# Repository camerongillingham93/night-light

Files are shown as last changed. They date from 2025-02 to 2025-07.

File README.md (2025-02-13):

# Firefly Night-Light
#### February, 13, 2025
 - Development REPO for a nightlight project using the AT-TINY1614 MCU and addressable LED strips
## Features 
 - PCB is designed to replace a standard wide-mouth Mason jar and have LED strips hanging from it resembling a jar full of fireflies
 - Top copper pad acts as a touch button to toggle the nightlight on/off and adjust brightness. Shake the jar for a firefly lightshow
 - Onboard LI-PO battery that is USB-C re-chargeable

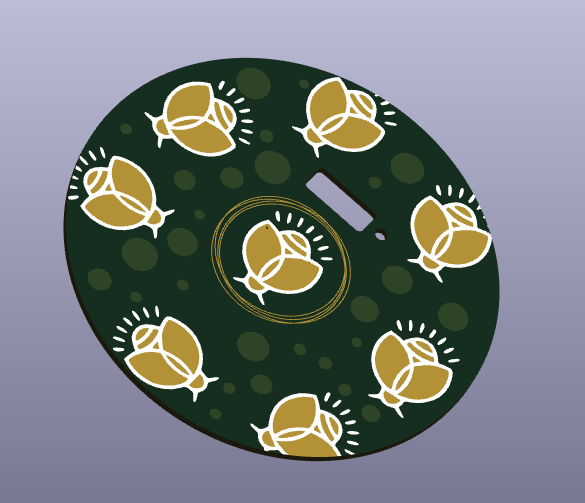
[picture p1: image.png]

<br>
*Rendering of Top of the night-light PCB*

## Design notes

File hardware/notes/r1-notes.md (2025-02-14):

# Nightlight Rev 1 Notes
### February, 13, 2025

## Assembly  Notes

- Get stencil and use hot plate for next order, voltage regulator was very challenging to hand solder and bridged many times before successfully soldering. 

- Was missing 10K 1210 SMT resistors from order, R1,R2,R6

- Need to think of a better method for attaching LED strips or use different part, they are very thin and challenging t

## Testing

Voltage regulator - PAM2401SCADJ
- Once soldered succesfully, swept the Vin range given by the data sheet and had a steady 5V output

Charge controller - MCP73831-2-OT
- Discharged a 3800 mAh 3.7 li-ion to 3.6V 
- scraped open the Vbatt trace leading to the charge controller to measure current
- Set up meters to measure Vbatt and Ibatt
- plugged in USB cable and monitored output 
- I out was 100mA and stayed at the current until Vbatt was 4.2V, At this point Ibatt started to lower until ~60mA and maintained a voltage of 4.2. This is as expected with a 10K resistor on PROG pin. 

MCU ATtiny1614-SS
- Flashed the ATTINY via serial UPDI with a cp2021 USB-UART module
- Instructions @ https://github.com/SpenceKonde/AVR-Guidance/blob/master/UPDI/jtag2updi.md
- tested by placing a LED across switch pin and running a BLINK script.
- for development i have broken out the serial pins on the MCU. USB to UART is solderded to a dedicated perf board that can switch between UPDI to program and serial comms for troubleshooting. 

## Next time TODO

- Ground was missed on charge controller IC
- Add decoupling caps to MCU
- add 0 OHM R to separate regulator and charge controller for testing
- Use a bi-colour LED on the STAT pin of the charge controller
- Use ADC on MCU to measure Vbatt and disable nightlight at low voltage threshold and prompt charge somehow, OR find a solution to use a pin from the power supply for some sort of LVD
    - Design a 2:1 Voltage divider on the ADC input. Although i dont think it is needed as a Vref can be either internal(selectable) or VDD, in which case place a 0ohm inline.
- find a better USB-C port that actually uses CC resistors so product will work with PD
- breakout serial pins for comms with the board
- try to wire up PTC to touch pad with 0ohm
- Add a reset button

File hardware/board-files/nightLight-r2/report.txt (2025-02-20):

Info: Processing symbol 'B1:myFootprintDesigns:fireflyTouch'.
Info: Processing symbol 'U3:Package_TO_SOT_SMD:SOT-23-5'.
Info: Processing symbol 'U2:Package_SO:SOIC-14_3.9x8.7mm_P1.27mm'.
Info: Processing symbol 'BT1:myFootprintDesigns:14500 Holder'.
Info: Processing symbol 'C1:Capacitor_SMD:C_1206_3216Metric'.
Info: Processing symbol 'SW2:Connector_PinHeader_2.54mm:PinHeader_2x01_P2.54mm_Vertical_SMD'.
Info: Processing symbol 'S1:PTS526_SM08_SMTR2_LFS:SW_PTS526_SM08_SMTR2_LFS'.
Info: Processing symbol 'C2:Capacitor_SMD:C_1206_3216Metric'.
Info: Processing symbol 'R11:Resistor_SMD:R_1206_3216Metric'.
Info: Processing symbol 'R10:Resistor_SMD:R_1206_3216Metric'.
Info: Processing symbol 'C3:Capacitor_SMD:C_1206_3216Metric'.
Info: Processing symbol 'C4:Capacitor_SMD:C_1206_3216Metric'.
Info: Processing symbol 'C5:Capacitor_SMD:C_1206_3216Metric'.
Info: Processing symbol 'R9:Resistor_SMD:R_1206_3216Metric'.
Info: Processing symbol 'R8:Resistor_SMD:R_1206_3216Metric'.
Info: Processing symbol 'C6:Capacitor_SMD:C_1206_3216Metric'.
Info: Processing symbol 'R7:Resistor_SMD:R_1206_3216Metric'.
Info: Processing symbol 'R6:Resistor_SMD:R_1206_3216Metric'.
Info: Processing symbol 'R5:Resistor_SMD:R_1206_3216Metric'.
Info: Processing symbol 'R4:Resistor_SMD:R_1206_3216Metric'.
Info: Processing symbol 'R3:Resistor_SMD:R_1206_3216Metric'.
Info: Processing symbol 'R2:Resistor_SMD:R_1206_3216Metric'.
Info: Processing symbol 'R1:Resistor_SMD:R_1206_3216Metric'.
Info: Processing symbol 'C7:Capacitor_SMD:C_1206_3216Metric'.
Info: Processing symbol 'L1:SRN2510BTA-2R2M:SRN2510BTA2R2M'.
Info: Processing symbol 'J8:Connector_PinSocket_2.54mm:PinSocket_1x05_P2.54mm_Vertical_SMD_Pin1Left'.
Info: Processing symbol 'J6:Connector_PinHeader_2.54mm:PinHeader_1x03_P2.54mm_Vertical_SMD_Pin1Left'.
Info: Processing symbol 'J5:myFootprintDesigns:USB-C_PWR'.
Info: Processing symbol 'J3:Connector_PinHeader_2.54mm:PinHeader_1x03_P2.54mm_Vertical_SMD_Pin1Left'.
Info: Processing symbol 'J2:Connector_PinHeader_2.54mm:PinHeader_1x03_P2.54mm_Vertical_SMD_Pin1Left'.
Info: Processing symbol 'J1:Connector_PinHeader_2.54mm:PinHeader_1x03_P2.54mm_Vertical_SMD_Pin1Left'.
Info: Processing symbol 'D1:IN-S124ARUW:LED_IN-S124ARUW'.
Info: Processing symbol 'IC1:PAM2401:SOP65P490X110-8N'.
Reconnected IC1 pin 3 from VBATT to Net-(IC1-VIN).
Connected C7 pin 2 to GND.
Add net LED_DATA.
Reconnected J1 pin 2 from Net-(J1-Pin_2) to LED_DATA.
Connected C7 pin 1 to +5V.
Updated C7 properties.
Updated C7 symbol association from  to /aaa6ea5b-403b-4111-be4f-55c8a439cf0b.
Added J5 (footprint 'myFootprintDesigns:USB-C_PWR').
Changed REF** reference designator to J5.
Changed J5 value from USB-C_PWR to USB_C_Receptacle_PowerOnly_6P.
Updated J5 symbol association from  to /313a628f-e523-4211-801d-f47782c87484.
Updated J5 properties.
Add net Net-(J5-CC1).
Connected J5 pin A5 to Net-(J5-CC1).
Connected J5 pin A9 to Net-(U3-V_{DD}).
Connected J5 pin A12 to GND.
Add net Net-(J5-CC2).
Connected J5 pin B5 to Net-(J5-CC2).
Changed C7 value from C_1206_3216Metric to 22uF.
Added J6 (footprint 'Connector_PinHeader_2.54mm:PinHeader_1x03_P2.54mm_Vertical_SMD_Pin1Left').
Changed REF** reference designator to J6.
Changed J6 value from PinHeader_1x03_P2.54mm_Vertical_SMD_Pin1Left to Conn_01x03.
Updated J6 symbol association from  to /cc5e9cfa-e928-4264-b735-3705385eb68d.
Updated J6 properties.
Add net PA_1.
Connected J6 pin 1 to PA_1.
Add net PA_2.
Connected J6 pin 2 to PA_2.
Add net PA_3.
Connected J6 pin 3 to PA_3.
Changed REF** reference designator to C7.
Added J8 (footprint 'Connector_PinSocket_2.54mm:PinSocket_1x05_P2.54mm_Vertical_SMD_Pin1Left').
Changed REF** reference designator to J8.
Changed J8 value from PinSocket_1x05_P2.54mm_Vertical_SMD_Pin1Left to Conn_01x05_Pin.
Updated J8 symbol association from  to /a5c941a7-82e7-435c-9ba5-a8ea3b5d0ae3.
Updated J8 properties.
Connected J8 pin 1 to GND.
Add net TX.
Connected J8 pin 2 to TX.
Add net RX.
Connected J8 pin 3 to RX.
Add net UPDI.
Connected J8 pin 4 to UPDI.
Connected J8 pin 5 to +5V.
Added C7 (footprint 'Capacitor_SMD:C_1206_3216Metric').
Reconnected L1 pin 1 from VBATT to Net-(IC1-VIN).
Connected C6 pin 2 to GND.
Changed R1 value from 10k to 1M.
Add net Send.
Reconnected R1 pin 1 from Net-(U2-PA5) to Send.
Reconnected R1 pin 2 from Net-(U2-PA6) to Return.
Connected C6 pin 1 to +5V.
Add net Tilt_SW.
Reconnected R2 pin 2 from Net-(U2-PA7) to Tilt_SW.
Updated C6 properties.
Reconnected R3 pin 1 from VBATT to Net-(IC1-VIN).
Updated C6 symbol association from  to /1a6fa1bd-9f4d-40e3-aad2-769d0811d651.
Changed C6 value from C_1206_3216Metric to 22uF.
Changed REF** reference designator to C6.
Added C6 (footprint 'Capacitor_SMD:C_1206_3216Metric').
Reconnected R7 pin 1 from Net-(U1-V+) to Net-(U3-V_{DD}).
Reconnected C5 pin 1 from Net-(U1-V+) to Net-(U3-V_{DD}).
Added R8 (footprint 'Resistor_SMD:R_1206_3216Metric').
Changed REF** reference designator to R8.
Changed R8 value from R_1206_3216Metric to 5.1k.
Updated R8 symbol association from  to /2a3b3306-2b1f-47dc-9f0e-92f4898f2bf4.
Updated R8 properties.
Connected R8 pin 1 to Net-(J5-CC2).
Connected R8 pin 2 to GND.
Add net Net-(U3-V_{DD}).
Added R9 (footprint 'Resistor_SMD:R_1206_3216Metric').
Changed REF** reference designator to R9.
Changed R9 value from R_1206_3216Metric to 5.1k.
Updated R9 symbol association from  to /3f4016df-daa6-43f8-9075-7b56907655ad.
Updated R9 properties.
Connected R9 pin 1 to Net-(J5-CC1).
Connected R9 pin 2 to GND.
Updated C2 symbol association from /f2f016f0-e33d-4f4f-93c3-e3167ada6333 to /1f779e93-5f75-473e-9afa-ae6fad9b06e3.
Added R10 (footprint 'Resistor_SMD:R_1206_3216Metric').
Changed REF** reference designator to R10.
Changed R10 value from R_1206_3216Metric to 10k.
Updated R10 symbol association from  to /bb20765d-0209-4473-9338-8d07f0b34927.
Updated R10 properties.
Connected R10 pin 1 to +5V.
Add net RST_SW.
Connected R10 pin 2 to RST_SW.
Changed C2 value from 22uF to 0.1uF.
Added R11 (footprint 'Resistor_SMD:R_1206_3216Metric').
Changed REF** reference designator to R11.
Changed R11 value from R_1206_3216Metric to 0.
Updated R11 symbol association from  to /f047d941-6963-4854-815e-351e46250964.
Updated R11 properties.
Connected R11 pin 1 to Net-(IC1-VIN).
Connected R11 pin 2 to VBATT.
Reconnected C1 pin 1 from VBATT to Net-(IC1-VIN).
Added S1 (footprint 'PTS526_SM08_SMTR2_LFS:SW_PTS526_SM08_SMTR2_LFS').
Changed REF** reference designator to S1.
Changed S1 value from SW_PTS526_SM08_SMTR2_LFS to PTS526_SM08_SMTR2_LFS.
Updated S1 symbol association from  to /87c368d1-e28a-492d-950a-39ae2efabe5e.
Updated S1 properties.
Connected S1 pin 1 to GND.
Connected S1 pin 3 to RST_SW.
Connected S1 pin 2 to GND.
Connected S1 pin 4 to RST_SW.
Add net Net-(IC1-VIN).
Reconnected SW2 pin 1 from Net-(U2-PA7) to Tilt_SW.
Reconnected B1 pin 1 from Net-(U2-PA6) to Return.
Add net Batt_M.
Reconnected U2 pin 2 from Net-(J1-Pin_2) to Batt_M.
Reconnected U2 pin 3 from Net-(U2-PA5) to Send.
Reconnected U2 pin 4 from Net-(U2-PA6) to Return.
Reconnected U2 pin 5 from Net-(U2-PA7) to Tilt_SW.
Reconnected U2 pin 6 from unconnected-(U2-PB3-Pad6) to RX.
Reconnected U2 pin 7 from unconnected-(U2-PB2-Pad7) to TX.
Reconnected U2 pin 8 from unconnected-(U2-PB1-Pad8) to LED_DATA.
Reconnected U2 pin 9 from unconnected-(U2-PB0-Pad9) to RST_SW.
Reconnected U2 pin 10 from Net-(J4-Pin_2) to UPDI.
Reconnected U2 pin 11 from unconnected-(U2-PA1-Pad11) to PA_1.
Reconnected U2 pin 12 from unconnected-(U2-PA2-Pad12) to PA_2.
Reconnected U2 pin 13 from unconnected-(U2-PA3-Pad13) to PA_3.
Add net Return.
Reconnected U3 pin 4 from Net-(U1-V+) to Net-(U3-V_{DD}).
Removed unused footprint U1.
Removed unused footprint J4.
Removed unused footprint REF**.
Removed unused footprint REF**.
Removed unused footprint REF**.
Removed unused footprint REF**.
Removed unused footprint REF**.
Removed unused footprint REF**.
Removed unused footprint REF**.
Removed unused net unconnected-(U2-PB3-Pad6).
Removed unused net unconnected-(U2-PB2-Pad7).
Removed unused net unconnected-(U2-PB1-Pad8).
Removed unused net Net-(J1-Pin_2).
Removed unused net Net-(J4-Pin_2).
Removed unused net Net-(U1-V+).
Removed unused net Net-(U2-PA5).
Removed unused net Net-(U2-PA6).
Removed unused net Net-(U2-PA7).
Removed unused net unconnected-(U2-PA1-Pad11).
Removed unused net unconnected-(U2-PA2-Pad12).
Removed unused net unconnected-(U2-PA3-Pad13).
Removed unused net unconnected-(U2-PB0-Pad9).
Error: J5 pad S1 not found in myFootprintDesigns:USB-C_PWR.
Error: J5 pad B9 not found in myFootprintDesigns:USB-C_PWR.
Error: J5 pad B12 not found in myFootprintDesigns:USB-C_PWR.

Info: Total warnings: 0, errors: 3.

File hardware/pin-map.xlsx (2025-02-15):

Night Light Pin Map
Pin Number | Pin Name | Use
1 | VDD | PWR
2 | PA4 | Vmeasure ADC1
3 | PA5 | Touch Send
4 | PA6 | Touch Return OR PTC
5 | PA7 | TILT SW
6 | PB3 | RX
7 | PB2 | TX
8 | PB1 | LED Data
9 | PB0 | Rst BTN (Software)
10 | PA0/RESET/UPDI | UPDI
11 | PA1 | spare
12 | PA2 | spare
13 | PA3 | spare
14 | GND | GND

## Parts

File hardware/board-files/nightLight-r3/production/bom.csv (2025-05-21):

Designator | Footprint | Quantity | Value | LCSC Part #
B1 | fireflyTouch | 1 | ~
BT1 | 14500 Holder | 1 | Battery_Cell
C1, C7 | 0805 | 2 | 0.1uF
C2, C3, C6 | 0805 | 3 | 22uF
C4, C5 | 0805 | 2 | 4.7uF
D1 | SOT23-R | 1 | BAT54C
FID1 | Fiducial_1.5mm_Mask3mm | 1 | Fiducial
IC1 | SOP65P490X110-8N | 1 | PAM2401SCADJ
IC2 | SON50P300X300X100-11N-D | 1 | MCP73123T-22SI_MF
J1 | USB-C_PWR | 1 | USB_C_Receptacle_PowerOnly_6P
J2 | PinSocket_1x05_P2.54mm_Vertical_SMD_Pin1Left | 1 | Conn_01x05_Pin
J3 | spares_1*3 | 1 | Conn_01x03
J4, J5, J6 | fairy_conn | 3 | Conn_01x03
L1 | SRN2510BTA2R2M | 1 | SRN2510BTA-2R2M
LED1 | INS124ARUW | 1 | IN-S124ARUW
Q1 | SOT-23 | 1 | AO3400A
Q2, Q3 | SOT-23 | 2 | AO3401A
R1, R13 | 0805 | 2 | 10K
R10, R8, R9 | 0805 | 3 | 5.1k
R11, R12, R14, R2, R3 | 0805 | 5 | 1M
R15, R16 | 0805 | 2 | 0
R4, R5 | 0805 | 2 | 750K
R6 | 0805 | 1 | 100K
R7 | 0805 | 1 | 1K
SW1 | PinHeader_2x01_P2.54mm_Vertical_SMD | 1 | TILT
U8 | SOIC-14_3.9x8.7mm_P1.27mm | 1 | ATtiny1614-SS

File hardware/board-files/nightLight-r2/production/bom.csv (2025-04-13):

Designator | Footprint | Quantity | Value | LCSC Part # | Mouser Cart | Already Have | JLC | Wal-Mart Batteries
B1 | fireflyTouch | 1 | ~ |  | N/A | X |  | https://www.walmart.ca/en/ip/12-Pack-AA-3-2-Volt-600-mAh-LiFePO4-14500-Batteries-14mm-x-50mm/5P39UR7DSS06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
BT1 | 14500 Holder | 1 | Battery_Cell |  | N/A | X
C1, C5, C6 | 0805 | 3 | 22uF |  | X
C2, C4 | 0805 | 2 | 4.7uF |  | X
C7 | 0805 | 1 | 0.1uF |  | X
FID1 | Fiducial_1.5mm_Mask3mm | 1 | Fiducial |  |  | X
IC1 | SOP65P490X110-8N | 1 | PAM2401SCADJ |  | X
IC2 | SON50P300X300X100-11N-D | 1 | MCP73123T-22SI_MF |  | X
J1 | USB-C_PWR | 1 | USB_C_Receptacle_PowerOnly_6P |  |  | X
J2, J3, J4 | PinHeader_1x03_P2.54mm_Vertical_SMD_Pin1Left | 3 | Conn_01x03 |  |  | X
J5 | spares_1*3 | 1 | Conn_01x03 |  |  | X
J6 | PinSocket_1x05_P2.54mm_Vertical_SMD_Pin1Left | 1 | Conn_01x05_Pin |  |  | X
L1 | SRN2510BTA2R2M | 1 | SRN2510BTA-2R2M |  | X
LED1 | INS124ARUW | 1 | IN-S124ARUW |  | X
R10, R9 | 0805 | 2 | 0 |  | X
R11, R12 | 0805 | 2 | 10k |  | X
R13 | 0805 | 1 | 1M |  | X
R2, R4, R5 | 0805 | 3 | 5.1k |  | X
R3, R8 | 0805 | 2 | 100K |  | X
R6 | 0805 | 1 | 1K |  | X
R7 | 0805 | 1 | 750K |  | X
S1 | SW_PTS526_SM08_SMTR2_LFS | 1 | PTS526_SM08_SMTR2_LFS |  | X
SW1 | PinHeader_2x01_P2.54mm_Vertical_SMD | 1 | TILT |  |  | X
U1 | SOT95P237X112-3N | 1 | MCP809T-270I_TT |  | X
U2 | SOIC-14_3.9x8.7mm_P1.27mm | 1 | ATtiny1614-SS |  | X
Total |  |  |  |  | 80 | 0 | 19.16 | 85.77 | 184.93
/unit |  |  |  |  | 8 |  | 3.83 | 7 | 18.83

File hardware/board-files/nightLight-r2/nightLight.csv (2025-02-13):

mouser | Reference | Qty | Value | Footprint | DNP
1 | B1 | 1 | ~ | myFootprintDesigns:fireflyTouch
2 | BT1 | 1 | Battery_Cell | myFootprintDesigns:14500 Holder
3 | C1, C2, C3 | 3 | 22uF | Capacitor_SMD:C_1206_3216Metric |  | X
4 | C4 | 1 | 10uF | Capacitor_SMD:C_1206_3216Metric |  | x
5 | C5 | 1 | 4.7uF | Capacitor_SMD:C_1206_3216Metric |  | x
6 | D1 | 1 | IN-S124ARUW | IN-S124ARUW:LED_IN-S124ARUW |  | x
7 | IC1 | 1 | PAM2401SCADJ | PAM2401:SOP65P490X110-8N |  | x
8 | J1, J2, J3, J4 | 4 | Conn_01x03 | Connector_PinHeader_2.54mm:PinHeader_1x03_P2.54mm_Vertical_SMD_Pin1Left
9 | L1 | 1 | SRN2510BTA-2R2M | SRN2510BTA-2R2M:SRN2510BTA2R2M |  | x
10 | R1, R2, R6 | 3 | 10k | Resistor_SMD:R_1206_3216Metric |  | x
11 | R3, R4 | 2 | 750K | Resistor_SMD:R_1206_3216Metric |  | x
12 | R5 | 1 | 100K | Resistor_SMD:R_1206_3216Metric |  | x
13 | R7 | 1 | 1K | Resistor_SMD:R_1206_3216Metric |  | x
14 | SW2 | 1 | TILT | Connector_PinHeader_2.54mm:PinHeader_2x01_P2.54mm_Vertical_SMD
15 | U1 | 1 | USB-C_PWR | myFootprintDesigns:USB-C_PWR |  | x
16 | U2 | 1 | ATtiny1614-SS | Package_SO:SOIC-14_3.9x8.7mm_P1.27mm
17 | U3 | 1 | MCP73831-2-OT | Package_TO_SOT_SMD:SOT-23-5

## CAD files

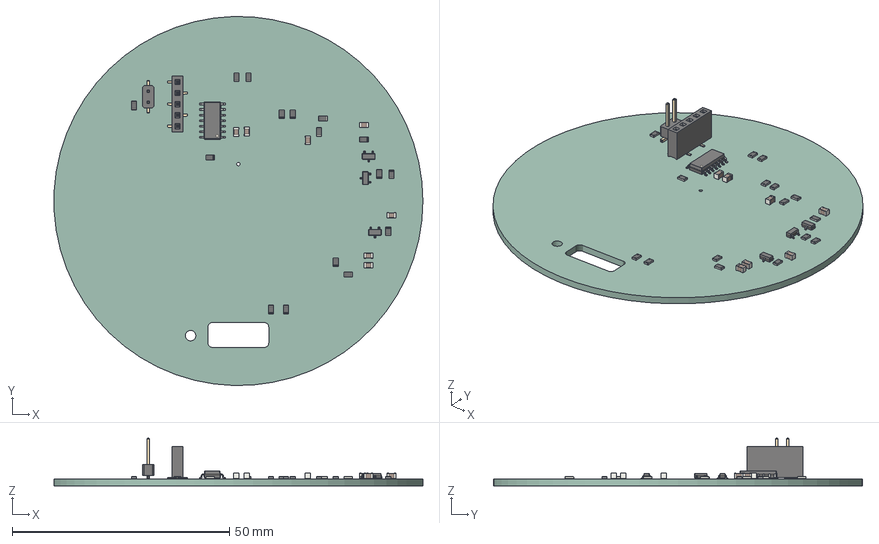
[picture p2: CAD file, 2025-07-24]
hardware/board-files/nightLight-r3/nightLight.step
84.9 x 85.0 x 11.0 mm
R_0805_2012Metric x 16
C_0805_2012Metric x 7
SOT_23 x 3
PinSocket_1x05_P254mm_Vertical_SMD_Pin1Left
PinHeader_2x01_P254mm_Vertical_SMD
SOIC_14_39x87mm_P127mm
nightLight PCB

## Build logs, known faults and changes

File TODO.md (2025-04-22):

# Nightlight Project - To-Do List 

## April 17, 2025
### Notes

- Have tested the Power supply and LVD circuit extensivley and realzied I misinterptetted How the EN pin of the voltage regulator works. When EN is pulled LOW it disables the operation of the regulator but still allows the input battery voltage through. This will not work for my design as it will allow the MCU an uniterupted path to discharge the battery below a safe re-operable battery voltage. Need to find a method of switching out the battery BEFORE the regulator.

- With this the program will just shut the device off when a threshold is reached instead of blinking red and entering into LOW_BATTERY mode as before. 

- With this new design I would like to enter a sleep mode whenever the light is off and X amount of time is passed. The tilt switch will be used to wake the device and the LED's will somehow alert the user the device has came out of sleep.  

### TODO
### Hardware 
- [X] Test new low voltage disconnect option, research how to contruct the latching ciruit, simulate, test on breadboard. 
  - P-Channel Mosfet to interupt battery power path, N-Channel Mosfet to control P-Channel. Will be turned off by a digital LOW on the MCU and turned on by the USB cable Vbus when the user plugs in the device to charge. 
#### Still to do from Last time 
- [X] Complete final revision of PCB
  - Remove RST switch
  - Add reverse protection diode
  - Change resistors for ADC to 1Mohm
  - Look for other things to improve
- [ ] Order boards 
  - Gold plating, exposed vias
  - Find a larger order quantity that is more cost effective
  - Look into JLC assembly? 
- [ ] Order Parts 
  - Ensure there is enough inventory for 10 boards
  - Look on ali for parts before mouser (Battery Holder, Tilt sw, etc.)
### Software
- [ ] Figure out sleep/standby mode when device is in "idle" state
#### Still to do from last time 
- [ ] features 
  - Fade lights back in after firefly affect 
  - Lengthen firefly effect

## April 15, 2025
### Notes
- Accidentally inserted battery backwards and burned up many components, tried re-working but decided to just assemble an entire new board. Have a working version of the firmware done, needs to be tested further and to find bugs and things to improve. Charge controller has yet to be fully tested. 

### TODO
### Hardware
- [X] Test Charge controller 
  - Complete multiple charge discharge cycles, and try to confirm charge current is around ~220MA
- [ ] Complete final revision of PCB
  - Remove RST switch
  - Add reverse protection diode
  - Change resistors for ADC to 1Mohm
  - Look for other things to improve
- [ ] Order boards 
  - Gold plating, exposed vias
  - Find a larger order quantity that is more cost effective
  - Look into JLC assembly? 
- [ ] Order Parts 
  - Ensure there is enough inventory for 10 boards
  - Look on ali for parts before mouser (Battery Holder, Tilt sw, etc.)
- [X] Lights on when supervisory cct opens regulator, current must be flowing into lights somehow
### Software
- [X] Refactor
  - Before fixing bugs and adding new features do a thorough clean and refactor of current revision.
    - Add titles to each file
    - remove debug statements
    - remove unused code
- [X] Improve Battery Life and monitoring 
  - Add Low and high thresholds to enter and exit LOW battery mode
  - Only check batery voltage every minute (Should help with hystersis issue)
  - Lower the low threshhold, get closer to the point where the supervisory cct will cut power
  - Play with other values to improve battery life but still provide a reasonable amount of light
    - Lower brightness limits
    - less LED's
  - Enter sleep in low Battery mode?
  - Slow down clock to 10MHz
- [ ] features 
  - Fade lights back in after firefly affect 
  - Lengthen firefly effect

## April  12, 2025
### Assembly
- PCB order came April 11, and assembled first board today. 
- Stencil worked well, cleaned up excess sodler with a pin before placing components 
- Had a bridge on IC2 placed on hot plate for a second time and dabbed with solder wick and it was solved.
### Initial Testing
- Was able to flash board and voltages were as expected
- firmware is working, am able to communicate with board via serial comms
- Soldered fairy lights on for the first time, not working. Either incorrect pin assignment or poor soldering
- Issues with LDO circuitry
  - Supervisory IC is working as expected, RST goes LOW when Vin < 2.5V
  - Vout of regulator was at 1.6 when EN was LOW, found that this was "PHANTOM POWER" from PIN_PA4 which is monitoring battery voltage via the ADC
  - As far as I know there is no way around this is i want o measure the voltage, but is lowered significatly by using the volatge divider with 100k ohm resistors
- Issue where touch pad only works reliably when touching board with other hand doesnt seem to be improved by grounding in R2
## Last time
- [X] **Continue firmware development**
  - Refactor things into a "controls class" and add shaking functionality along with designing the firefly light show
- [X] **Continue PCB review** 
  - Eliminate all errors and continue to look things over for potential improvements
  - Prep Fabrication files for odering
  - Find any ways to lower order cost (coupons, vias price,quanity)
- [X] Finish prepping mouser order
## March 15, 2025
### This Time
- [ ] **Continue firmware development**
  - Refactor things into a "controls class" and add shaking functionality along with designing the firefly light show
- [ ] **Continue PCB review** 
  - Eliminate all errors and continue to look things over for potential improvements
  - Prep Fabrication files for odering
  - Find any ways to lower order cost (coupons, vias price,quanity)
- [ ] Finish prepping mouser order

### Last Time
- [X] **Continue firmware development** (focus on touch reliability)  
  - Improve **`CapTouch` class**  
  - _Got to the point where toggling the LEDS with the touch button is wrking well along with long presses_
- [x] **Confirm charge controller compatibility** with LiFePO4 batteries
  -_Did not work, decided to re-design with a  new charge controller designed for LIFEPO4_
- [x] **Continue PCB review**  
  - _Made a mistake and had components too close to PCB edge, had to redo layout_
    - _Moved components outside of area surrouding perimeter_
    - _Improved grounding by adding a Bottom Copper pour and dropping vias thoughout PCB, also made a keepout zone beneath the elctrode and kept traces to the elctrode as short as possible_
    - _Added a PPTC fuse between battery and regulator_

## March 11, 2025

### This Time
- [ ] **Continue firmware development** (focus on touch reliability)  
  - Improve **`CapTouch` class**  
- [ ] **Confirm charge controller compatibility** with LiFePO4 batteries 
- [x] **Continue PCB review**  

### Last Time  
- [x] **Build a new test board** (MCU + essential components)  
  - Test **LEDs, Touch, and Tilt switch**  
  - Serial communication issues persist on the current board  
- [ ] **Confirm charge controller compatibility** with LiFePO4 batteries  
- [ ] **Continue firmware development** (focus on touch reliability)  
  - Improve **`CapTouch` class**  
  - Draft an **updated flowchart** (on ferry)  
- [X] **Meet Phil (Friday)**  
  - Discuss **LED strips & USB-C pinout**  
- [ ] **Continue PCB review**  

## February 25, 2025  

### This Time  
- [ ] **Build a new test board** (MCU + essential components)  
  - Test **LEDs, Touch, and Tilt switch**  
  - Serial communication issues persist on the current board  
- [ ] **Confirm charge controller compatibility** with LiFePO4 batteries  
- [ ] **Continue firmware development** (focus on touch reliability)  
  - Improve **`CapTouch` class**  
  - Draft an **updated flowchart** (on ferry)  
- [ ] **Meet Phil (Friday)**  
  - Discuss **LED strips & USB-C pinout**  
- [ ] **Continue PCB review**  

### Last Time (February 21, 2025)  
- [x] **Decided to monitor battery voltage via MCU ADC**  
  - Voltage divider optional if direct measurement is unstable  
- [x] **First draft of PCB finished**  
  - Will get **Aaron/Phil to review** before ordering Rev2  
- [x] **Firmware project started**  
  - Initial tests for **onboard PTC** were inconclusive  

---

## February 21, 2025  

### This Time  
- [ ] **Test PTC and begin writing firmware R1**  
  - Start with a **flowchart or pseudo-code**  
- [ ] **Continue reviewing and editing PCB**  
  - Ask someone else to look it over  
- [ ] **Figure out how to attach LEDs to the board**  
  - Talk to Phil  
- [ ] **Look at inventory and create BOM for Rev2** (low priority)  

### Last Time (February 13, 2025)  
- [x] **Could not find a solution directly using the charge controller or regulator**  
  - Decided to monitor voltage using **MCU ADC** instead  
  - Added a voltage divider in case it's necessary  
- [x] **First draft of PCB completed**  
  - Plan to review it over the next week and get feedback from Aaron or Phil  
- [x] **Firmware project created**  
  - Initial tests for onboard PTC  

---

## February 13, 2025  

### This Time  
- [ ] **Find a solution to prevent over-drawing from the battery**  
  - Either monitor with MCU or use LVD in power supply/charge controller  
- [ ] **Begin PCB layout for Rev2**  
  - Reference Rev1 notes  
- [ ] **Start writing firmware**  
  - Figure out **PTC**  
  - Start with **flowchart or pseudo-code**  

### Last Time  
- [x] **Started working on Rev1 firmware**  
- [x] **Confirmed initial hardware functionality**

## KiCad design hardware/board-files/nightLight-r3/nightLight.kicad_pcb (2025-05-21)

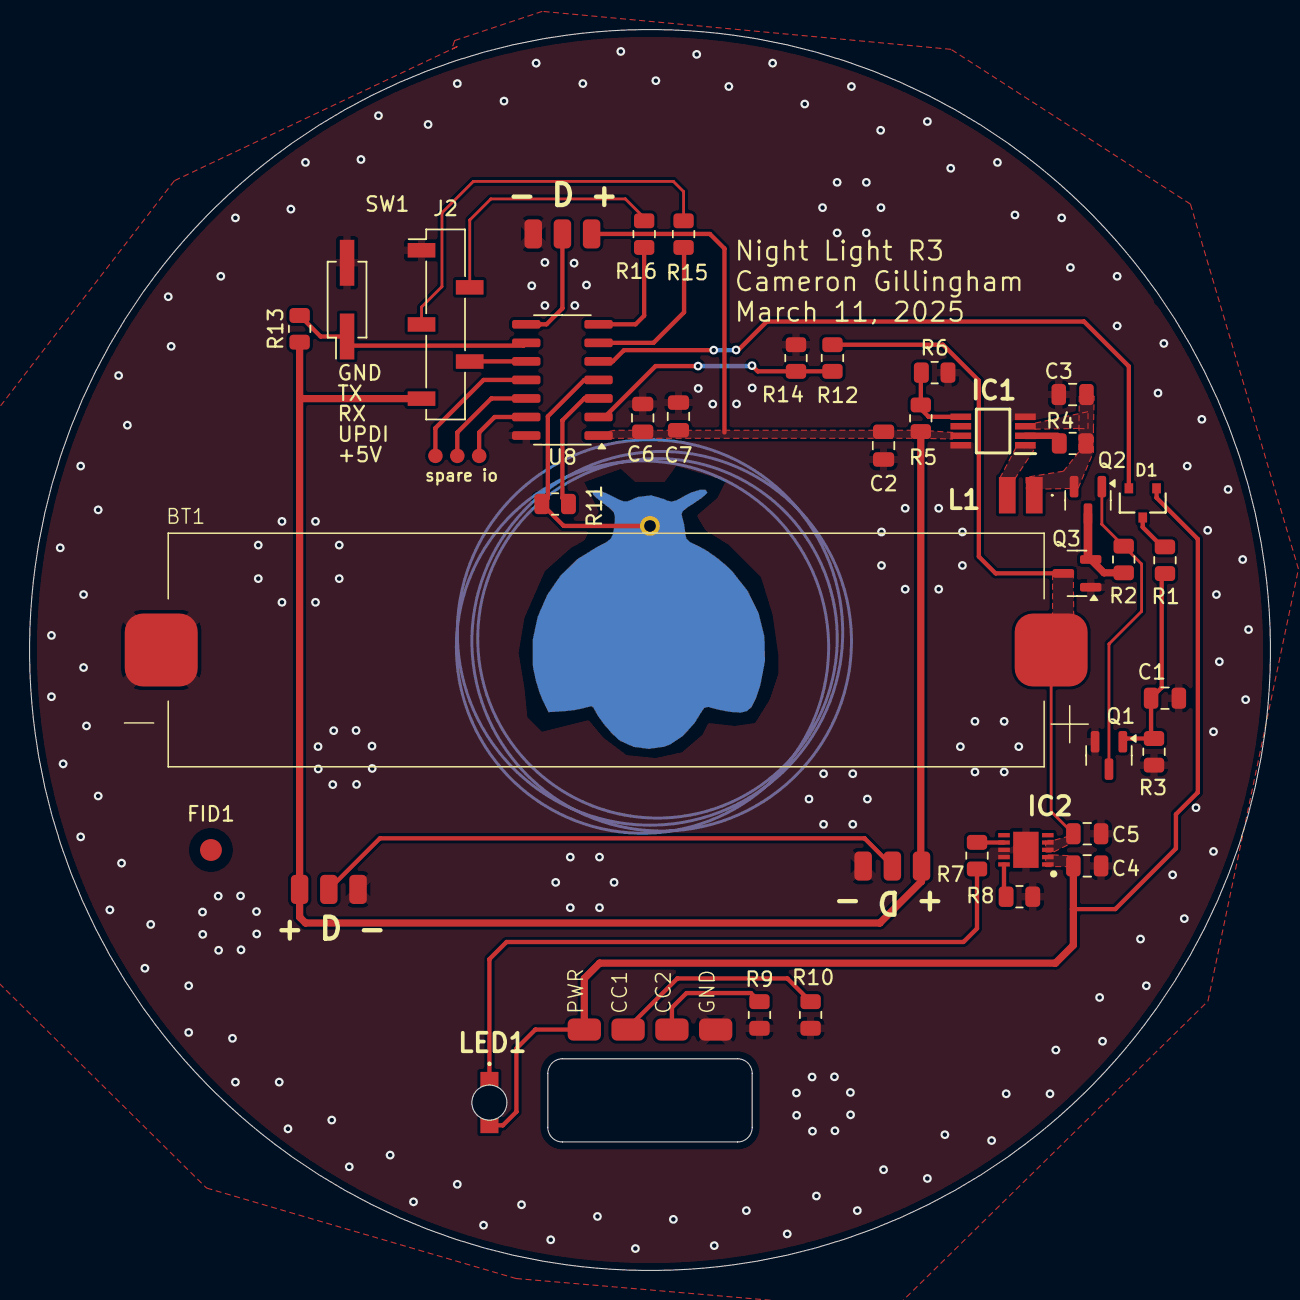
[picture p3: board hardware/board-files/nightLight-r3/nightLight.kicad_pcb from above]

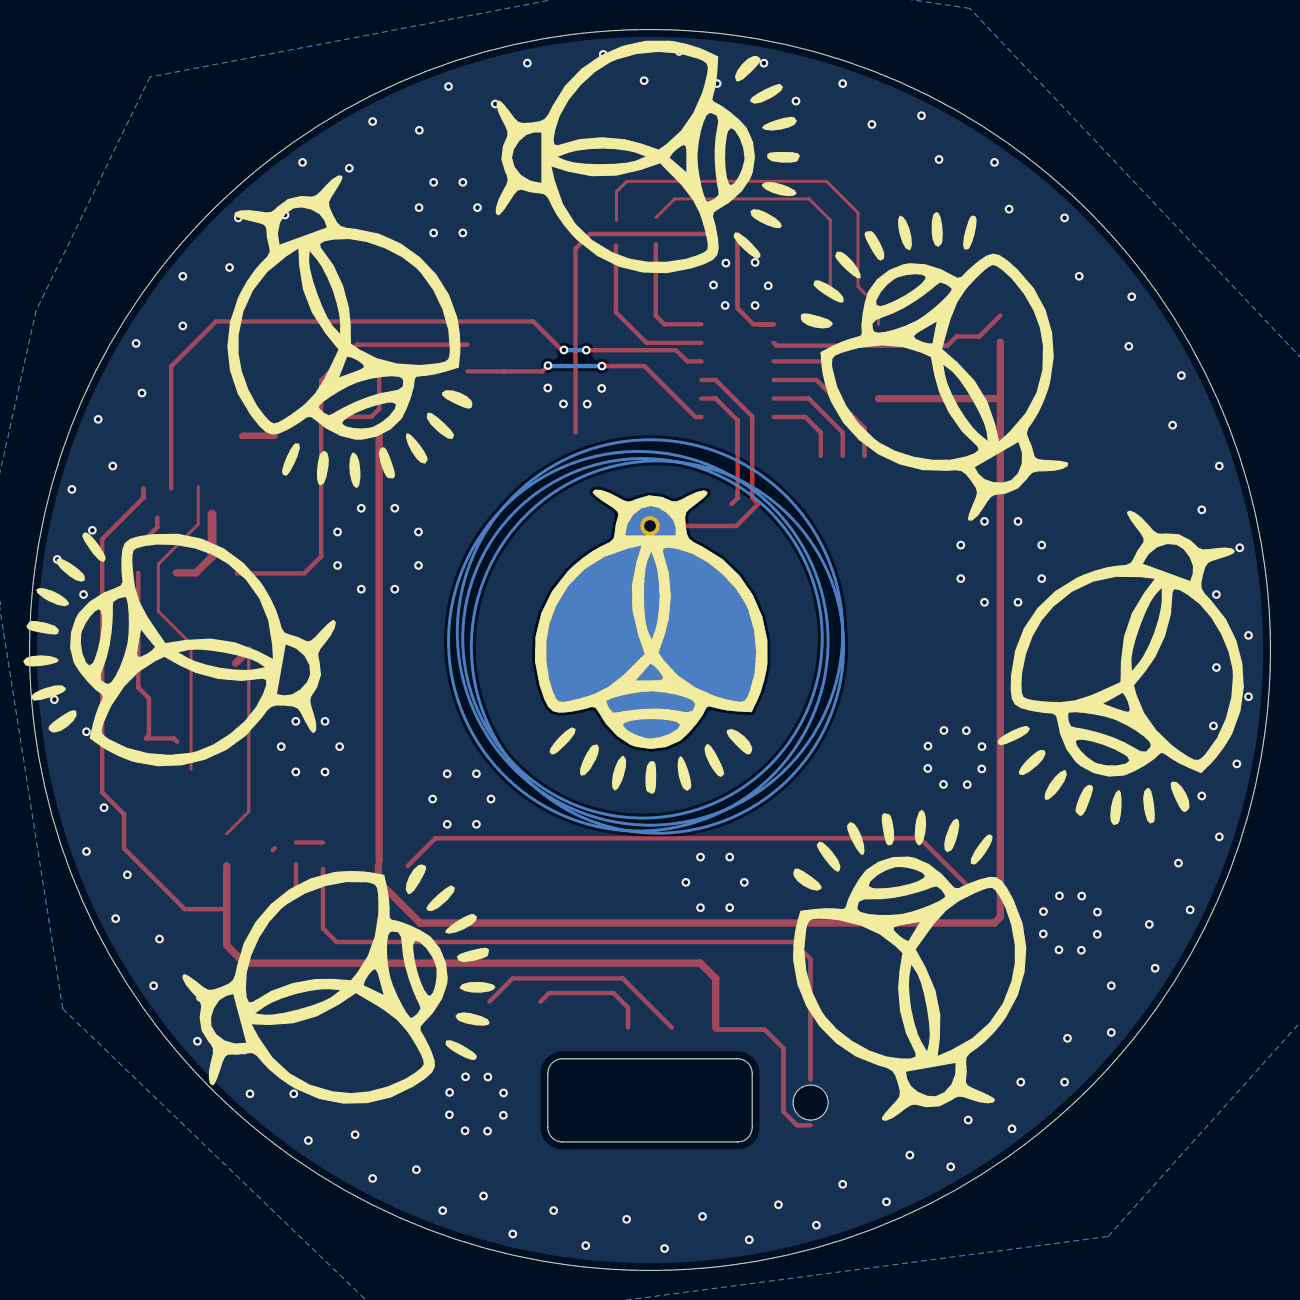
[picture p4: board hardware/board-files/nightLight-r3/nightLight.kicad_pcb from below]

Board: 2 copper layers, 85.0 x 85.0 mm, 49 parts (8 on the bottom side), 32 nets.

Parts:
B1: fireflyTouch
BT1: Battery_Cell; 14500 Holder
C1, C7: 0.1uF; C_0805_2012Metric
C2, C3, C6: 22uF; C_0805_2012Metric
C4, C5: 4.7uF; C_0805_2012Metric
D1: BAT54C; SOT23-R
FID1: Fiducial; Fiducial_1.5mm_Mask3mm
IC1: PAM2401SCADJ; SOP65P490X110-8N
IC2: MCP73123T-22SI_MF; SON50P300X300X100-11N-D
J1: USB_C_Receptacle_PowerOnly_6P; USB-C_PWR
J2: Conn_01x05_Pin; PinSocket_1x05_P2.54mm_Vertical_SMD_Pin1Left
J3: Conn_01x03; spares_1*3
J4, J5, J6: Conn_01x03; fairy_conn
L1: SRN2510BTA-2R2M; SRN2510BTA2R2M
LED1: IN-S124ARUW; INS124ARUW
Q1: AO3400A; SOT-23
Q2, Q3: AO3401A; SOT-23
R1: 10K; R_0805_2012Metric
R2, R3, R11, R12, R14: 1M; R_0805_2012Metric
R4, R5: 750K; R_0805_2012Metric
R6: 100K; R_0805_2012Metric
R7: 1K; R_0805_2012Metric
R8: 5.1K; R_0805_2012Metric
R9, R10: 5.1k; R_0805_2012Metric
R13: 10k; R_0805_2012Metric
R15, R16: 0; R_0805_2012Metric
SW1: TILT; PinHeader_2x01_P2.54mm_Vertical_SMD
U1, U2, U3, U4, U5, U6, U7: fireflyTouchNB
U8: ATtiny1614-SS; SOIC-14_3.9x8.7mm_P1.27mm

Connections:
+5V: C2.1, C6.1, C7.1, IC1.7 (OUT), J2.5, J4.1, J5.1, J6.1, R5.2, R13.1, U8.1 (VCC)
/Charge Controller/Vbatt: BT1.1 (+), C5.1, IC2.3 (VBAT_1), IC2.4 (VBAT_2), Q3.3 (D), R12.1
/Charge Controller/Vbus: C4.1, D1.1, IC2.1 (VDD_1), IC2.2 (VDD_2), J1.A9 (VBUS), LED1.2 (A)
/MCU/BATT_M: R12.2, R14.1, U8.2 (PA4)
/MCU/FET_CONTROL: D1.2, U8.5 (PA7)
/MCU/LED_DATA: J4.2, U8.8 (PB1)
/MCU/PA_1: J3.1, U8.11 (PA1)
/MCU/PA_2: J3.2, U8.12 (PA2)
/MCU/PA_3: J3.3, U8.13 (PA3)
/MCU/RETURN: B1.1, R11.2, U8.4 (PA6)
/MCU/RX: R15.1, U8.6 (PB3)
/MCU/SEND: R11.1, U8.3 (PA5)
/MCU/TILT_SW: R13.2, SW1.1, U8.9 (PB0)
/MCU/TX: R16.1, U8.7 (PB2)
/MCU/UPDI: J2.4, U8.10 (~RESET/PA0)
GND: BT1.2 (-), C1.2, C2.2, C3.2, C4.2, C5.2, C6.2, C7.2, IC1.4 (AGND), IC1.8 (PGND), IC2.8 (VSS_1), IC2.9 (VSS_2), IC2.11 (EP), J1.A12 (GND), J2.1, J4.3, J5.3, J6.3, Q1.2 (S), Q3.1 (G), R3.2, R6.1, R8.2, R9.2, R10.2, R14.2, SW1.2, U8.14 (GND)
unnamed: D1.3, R1.2
unnamed: IC1.2 (EN), R4.2
unnamed: IC1.5 (FB), R5.1, R6.2
unnamed: IC1.1 (LX), L1.2
unnamed: C3.1, IC1.3 (VIN), L1.1, Q2.2 (S), R4.1
unnamed: IC2.10 (PROG), R8.1
unnamed: IC2.7 (STAT), R7.2
unnamed: J1.A5 (CC1), R10.1
unnamed: J1.B5 (CC2), R9.1
unnamed: J2.2, R16.2
unnamed: J2.3, R15.2
unnamed: J5.2, J6.2
unnamed: LED1.1 (K), R7.1
unnamed: Q1.3 (D), Q2.1 (G), R2.2
unnamed: C1.1, Q1.1 (G), R1.1, R3.1
unnamed: Q2.3 (D), Q3.2 (S), R2.1

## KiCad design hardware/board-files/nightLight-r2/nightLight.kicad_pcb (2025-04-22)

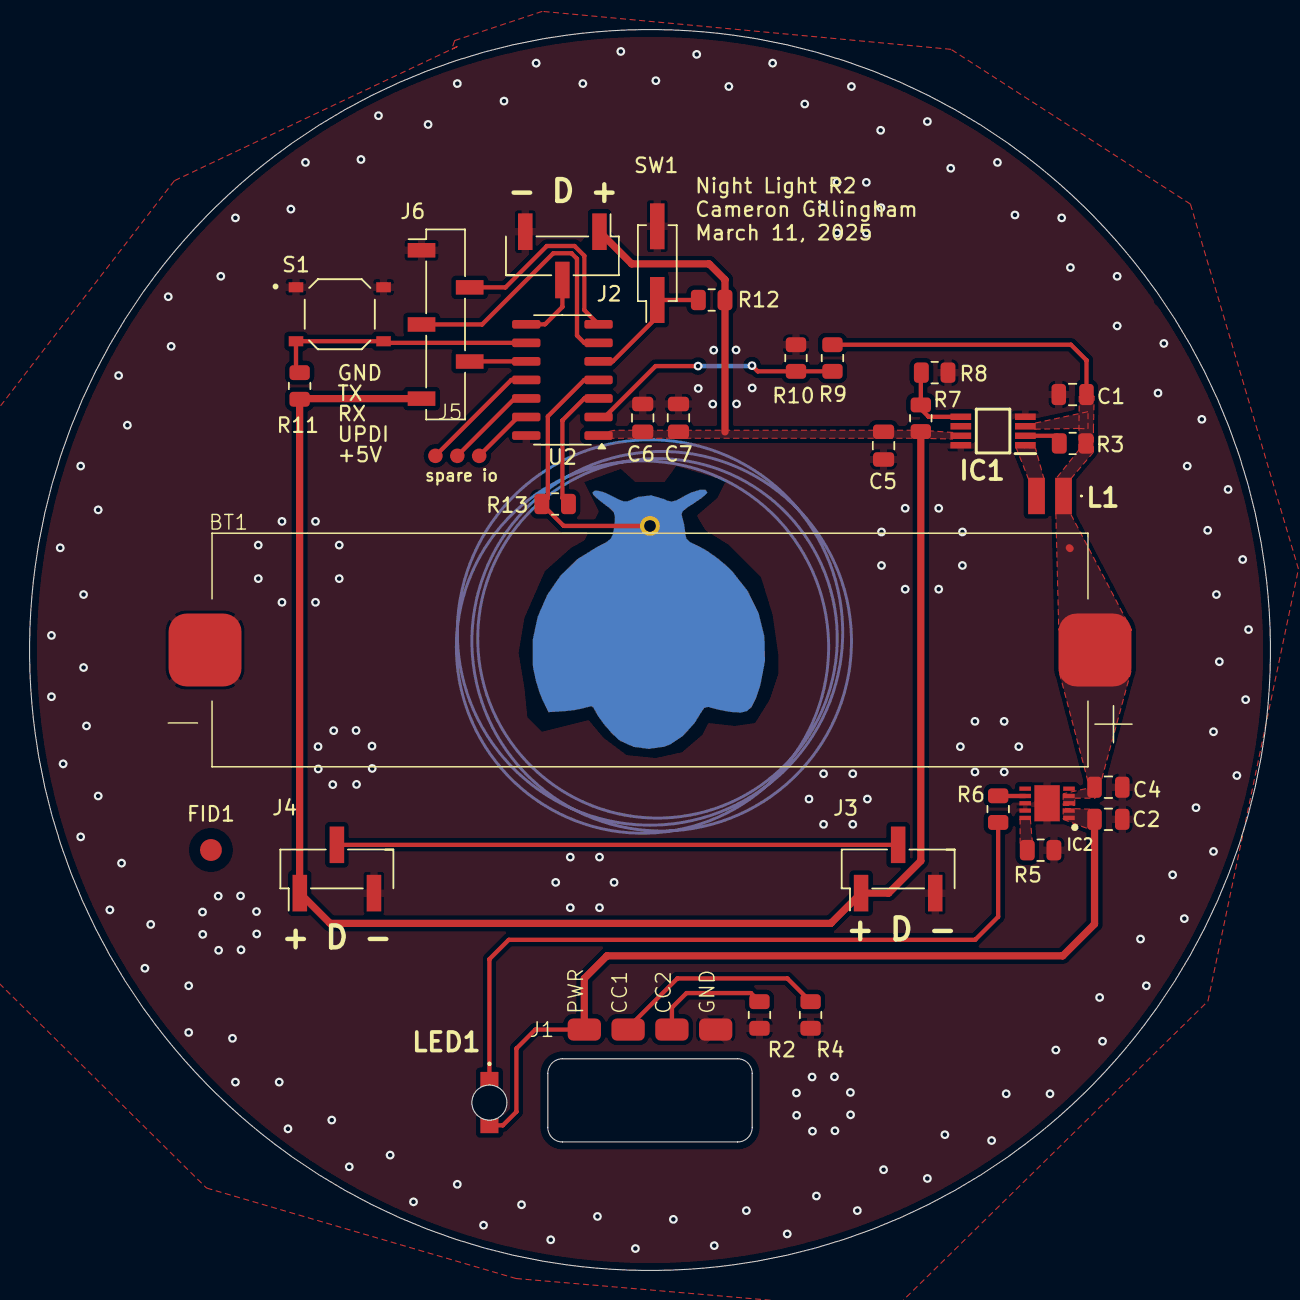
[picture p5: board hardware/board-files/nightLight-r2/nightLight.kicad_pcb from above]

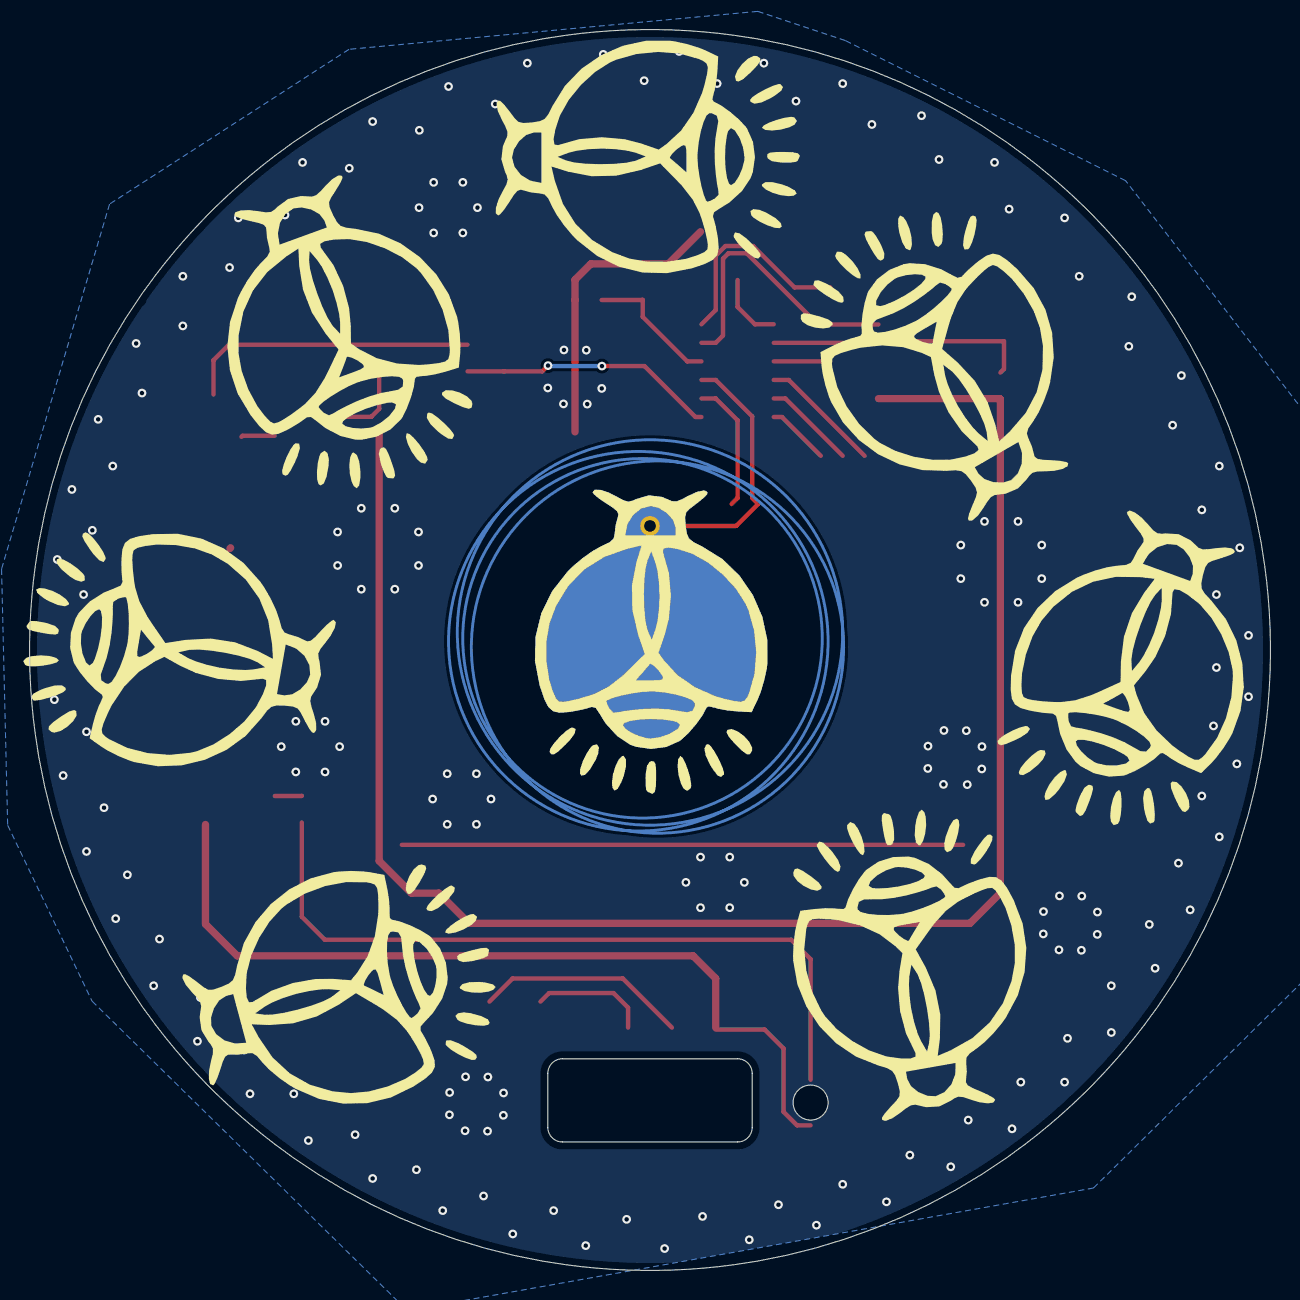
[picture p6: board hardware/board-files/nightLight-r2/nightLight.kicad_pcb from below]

Board: 2 copper layers, 85.0 x 85.0 mm, 41 parts (8 on the bottom side), 25 nets.

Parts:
B1: fireflyTouch
BT1: Battery_Cell; 14500 Holder
C1, C5, C6: 22uF; C_0805_2012Metric
C2, C4: 4.7uF; C_0805_2012Metric
C7: 0.1uF; C_0805_2012Metric
FID1: Fiducial; Fiducial_1.5mm_Mask3mm
IC1: PAM2401SCADJ; SOP65P490X110-8N
IC2: MCP73123T-22SI_MF; SON50P300X300X100-11N-D
J1: USB_C_Receptacle_PowerOnly_6P; USB-C_PWR
J2, J3, J4: Conn_01x03; PinHeader_1x03_P2.54mm_Vertical_SMD_Pin1Left
J5: Conn_01x03; spares_1*3
J6: Conn_01x05_Pin; PinSocket_1x05_P2.54mm_Vertical_SMD_Pin1Left
L1: SRN2510BTA-2R2M; SRN2510BTA2R2M
LED1: IN-S124ARUW; INS124ARUW
R2, R4: 5.1k; R_0805_2012Metric
R3, R7: 750K; R_0805_2012Metric
R5: 5.1K; R_0805_2012Metric
R6: 1K; R_0805_2012Metric
R8: 100K; R_0805_2012Metric
R9, R10: 0; R_0805_2012Metric
R11, R12: 10k; R_0805_2012Metric
R13: 1M; R_0805_2012Metric
S1: PTS526_SM08_SMTR2_LFS; SW_PTS526_SM08_SMTR2_LFS
SW1: TILT; PinHeader_2x01_P2.54mm_Vertical_SMD
U2: ATtiny1614-SS; SOIC-14_3.9x8.7mm_P1.27mm
U3, U4, U5, U6, U7, U8, U9: fireflyTouchNB

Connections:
+5V: C5.1, C6.1, C7.1, IC1.7 (OUT), J2.1, J3.1, J4.1, J6.5, R7.2, R11.1, R12.1, U2.1 (VCC)
Batt_M: R9.2, R10.1, U2.2 (PA4)
GND: BT1.2 (-), C1.2, C2.2, C4.2, C5.2, C6.2, C7.2, IC1.4 (AGND), IC1.8 (PGND), IC2.8 (VSS_1), IC2.9 (VSS_2), IC2.11 (EP), J1.A12 (GND), J2.3, J3.3, J4.3, J6.1, R2.2, R4.2, R5.2, R8.1, R10.2, S1.1, S1.2, SW1.2, U2.14 (GND)
LED_DATA: J2.2, U2.8 (PB1)
unnamed: IC1.2 (EN), R3.2
unnamed: IC1.5 (FB), R7.1, R8.2
unnamed: IC1.1 (LX), L1.2
unnamed: IC2.10 (PROG), R5.1
unnamed: IC2.7 (STAT), R6.2
unnamed: C2.1, IC2.1 (VDD_1), IC2.2 (VDD_2), J1.A9 (VBUS), LED1.2 (A)
unnamed: J1.A5 (CC1), R4.1
unnamed: J1.B5 (CC2), R2.1
unnamed: J3.2, J4.2
unnamed: LED1.1 (K), R6.1
PA_1: J5.1, U2.11 (PA1)
PA_2: J5.2, U2.12 (PA2)
PA_3: J5.3, U2.13 (PA3)
RST_SW: R11.2, S1.3, S1.4, U2.9 (PB0)
RX: J6.3, U2.6 (PB3)
Return: B1.1, R13.2, U2.4 (PA6)
Send: R13.1, U2.3 (PA5)
TX: J6.2, U2.7 (PB2)
Tilt_SW: R12.2, SW1.1, U2.5 (PA7)
UPDI: J6.4, U2.10 (~RESET/PA0)
VBATT: BT1.1 (+), C1.1, C4.1, IC1.3 (VIN), IC2.3 (VBAT_1), IC2.4 (VBAT_2), L1.1, R3.1, R9.1

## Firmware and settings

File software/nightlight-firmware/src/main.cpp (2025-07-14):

/**
 * Night Light Firmware V1 - Main Controller
 * -----------------------------------------
 * Main program flow controlling a touch-sensitive LED night light with:
 * - Touch sensor for on/off toggling and brightness adjustment (via long press)
 * - Shake detection for special "firefly" effects
 * - LED strip control for various effects
 * - Power saving with sleep mode after inactivity
 * - Hard power cutoff for battery protection (no warning system)
 *
 * @authors Cameron Gillingham, Claude AI
 * @version 1.2
 */

#include "LEDController.h"
#include "config.h"
#include "controls.h"
#include "powerControl.h"
#include <Arduino.h>

// Create sensor: sense pin, reference pin, threshold, debounce count
TouchSensor touchSensor(sensePin, refPin, touchThreshold, 5);
LEDController strip(LED_PIN, NUM_PIXELS);
Shake shake(tiltSW);
PowerController powerControl(POWER_CONTROL_PIN, strip);

// Variables for touch detection
bool lastTouchState = false;
bool currentTouchState = false;
unsigned long lastDebounceTime = 0;
unsigned long debounceDelay = 10; // Debounce time in milliseconds

void setup() {
  Serial.begin(9600);
  delay(100); // Short delay for serial to initialize

  // Initialize power controller
  powerControl.begin();
  powerControl.setInactivityTimeout(SLEEP_TIMEOUT_MS);

  // Initialize touch sensor
  touchSensor.begin();

  // Initial calibration - hold for 1 second to get baseline
  delay(1000);
  touchSensor.calibrate(10);

  // Initialize the LED strip
  strip.begin();

  // Initialize shake sensor
  shake.begin();
  shake.setShakeThreshold(5);
  shake.setShakeWindow(900);
}

void loop() {
  // Check if we're in sleep mode - skip normal processing if so
  if (powerControl.isInSleepMode()) {
    // In sleep mode, control is handed over to the power controller
    // and interrupts. Very little code here will execute until wake-up.
    powerControl.update();
    return;
  }

  // Read battery voltage and update power controller
  uint16_t rawADC = analogRead(battMeasure);
  float batteryVoltage = (rawADC / 1023.0) * 5 * 2;
  powerControl.updateBatteryStatus(batteryVoltage);

  // Skip all control processing if effect is running
  if (strip.isEffectRunning()) {
    delay(20);                       // Small delay for stability
    powerControl.registerActivity(); // Count effect runtime as activity
    return;
  }

  // Detect shake only when lights are ON and no effect is running
  if (strip.getState() && !strip.isEffectRunning() && shake.detectShake()) {
    strip.fireflyEffect();
    powerControl.registerActivity(); // Count effect trigger as activity
    return;
  }

  // Update touch sensor state for long press detection
  touchSensor.update();

  // Check if the electrode is touched
  bool isTouched = touchSensor.isTouched();

  // Any touch registers as activity
  if (isTouched) {
    powerControl.registerActivity();
  }

  // Check for long press and adjust brightness if active
  if (touchSensor.isLongPress()) {
    // Ensure lights are on when adjusting brightness
    if (!strip.getState()) {
      strip.setState(true);
    }

    // Get brightness value
    uint8_t wavebrightness = touchSensor.getTriangleWaveBrightness();

    // Update brightness
    strip.setBrightness(wavebrightness);
  }

  // Debounce the touch reading
  if (isTouched != lastTouchState) {
    lastDebounceTime = millis();
  }

  // Only change LED state if debounce time has passed
  if ((millis() - lastDebounceTime) > debounceDelay) {
    if (isTouched != currentTouchState) {
      currentTouchState = isTouched;

      // Only toggle if touch ended (released) AND it was NOT a long press
      if (isTouched == false && touchSensor.wasLongPress() == false) {
        strip.toggle();
        powerControl.registerActivity();
      }
    }
  }

  // Update last touch state
  lastTouchState = isTouched;

  // Let power controller check for sleep conditions
  powerControl.update();

  delay(20); // Small delay for stability
}

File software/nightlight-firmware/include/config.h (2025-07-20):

#ifndef CONFIG_H
#define CONFIG_H

// Pin definitions and constants

// Touch Sensor Pins and Threshold
#define sensePin PIN_PA5
#define refPin PIN_PA6
#define tiltSW PIN_PB0
#define touchThreshold 5

#define battMeasure PIN_PA4

// NeoPixel LED Strip Setup
#define LED_PIN PIN_PB1
#define NUM_PIXELS 10

// Brightness control
#define BRIGHTNESS_STEP 7
#define MIN_BRIGHTNESS 30
#define MAX_BRIGHTNESS 255

// Power management settings
#define POWER_CONTROL_PIN PIN_PA7
#define SLEEP_TIMEOUT_MS                                                       \
  30000 // 180000        // 3 minutes of inactivity before sleep
#define CRITICAL_BATTERY_THRESHOLD 2.8 // Volts - hard shutdown
#define WAKEUP_BATTERY_THRESHOLD 2.9   // Volts - can wake up again (hysteresis)
#define WAKEUP_TILT_DURATION 3000      // 3 seconds upside down to wake up

#endif

// **IMPORTANT: Double-check these pin numbers against your ATtiny1614 board's
// pinout!**
// sensePin: PA5
// refPin:   PA6
// tiltSW:   PB0
// battMeasure: PA4
// LED_PIN:  PB1
// POWER_CONTROL_PIN: PA7

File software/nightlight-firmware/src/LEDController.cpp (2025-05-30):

/**
 * Night Light Firmware V1 - LED Controller
 * ---------------------------------------
 * Controls LED strip operations including:
 * - Basic state management (on/off, brightness, color)
 * - Special effects including:
 *   - Low battery warning (pulsing red)
 *   - Firefly effect (random soft yellow-green flashes)
 * - Effect state management
 *
 * @authors Cameron Gillingham, Claude AI
 * @version 1.0
 */

#include "LEDController.h"
#include <Arduino.h>

LEDController::LEDController(uint8_t pin, uint16_t numPixels)
    : strip(numPixels, pin, NEO_GRB + NEO_KHZ800), ledsOn(false),
      brightness(220), red(160), green(255), blue(30), effectRunning(false),
      effectStartTime(0) {}

void LEDController::begin() {
  strip.begin();
  strip.show(); // Ensure all LEDs are off at startup
}

void LEDController::setState(bool state) {
  if (ledsOn != state) { // Prevent redundant updates
    ledsOn = state;
    updateStrip();
  }
}

void LEDController::toggle() {
  ledsOn = !ledsOn;
  updateStrip();
}

void LEDController::setBrightness(uint8_t newBrightness) {
  if (brightness != newBrightness) { // Avoid unnecessary updates
    brightness = newBrightness;
    updateStrip();
  }
}

void LEDController::setColor(uint8_t r, uint8_t g, uint8_t b) {
  red = r;
  green = g;
  blue = b;
  updateStrip();
}

void LEDController::updateStrip() {

  uint32_t color;
  if (ledsOn) {
    // Apply brightness to each color component
    uint8_t r = (red * brightness) / 255;
    uint8_t g = (green * brightness) / 255;
    uint8_t b = (blue * brightness) / 255;
    color = strip.Color(r, g, b);

  } else {
    color = strip.Color(0, 0, 0);
  }

  for (int i = 0; i < strip.numPixels(); i++) {
    strip.setPixelColor(i, color);
  }

  strip.show();
}

bool LEDController::isEffectRunning() { return effectRunning; }

void LEDController::lowBattery() {
  // Save the current state to restore later
  bool previousState = ledsOn;
  uint8_t prevRed = red;
  uint8_t prevGreen = green;
  uint8_t prevBlue = blue;
  uint8_t prevBrightness = brightness;

  // R and G are backwards???
  red = 0;
  green = 255;
  blue = 0;

  // Number of steps for fade in/out
  const int fadeSteps = 25;
  // Longer duration for each pulse
  const int pulseDelay = 15; // milliseconds per fade step

  // Pulse three times
  for (int pulse = 0; pulse < 3; pulse++) {
    // Fade in
    for (int i = 0; i < fadeSteps; i++) {
      brightness = (i * 255) / fadeSteps; // Calculate brightness from 0 to 255
      ledsOn = true;
      updateStrip();
      delay(pulseDelay);
    }

    // Hold at full brightness briefly
    delay(100);

    // Fade out
    for (int i = fadeSteps - 1; i >= 0; i--) {
      brightness = (i * 255) / fadeSteps; // Calculate brightness from 255 to 0
      updateStrip();
      delay(pulseDelay);
    }

    // Pause between pulses if not the last one
    if (pulse < 2) {
      ledsOn = false;
      updateStrip();
      delay(300); // Longer pause between pulses
    }
  }

  // Ensure LEDs are off at the end
  ledsOn = false;
  updateStrip();

  // Restore previous color and brightness settings
  red = prevRed;
  green = prevGreen;
  blue = prevBlue;
  brightness = prevBrightness;

  // Don't restore previous on/off state - in low battery mode we want to keep
  // lights off ledsOn = previousState;  // We're not restoring this
  updateStrip();
}


void LEDController::fireflyEffect() {
  // Save the current state to restore later
  bool previousState = ledsOn;
  uint8_t prevRed = red;
  uint8_t prevGreen = green;
  uint8_t prevBlue = blue;
  uint8_t prevBrightness = brightness;

  // Set effect running flag
  effectRunning = true;

  // Colors for fireflies - warmish green-yellow
  const uint8_t fireflyRed = 160;
  const uint8_t fireflyGreen = 255;
  const uint8_t fireflyBlue = 30;

  // Effect duration and parameters
  const unsigned long effectDuration = 5000; // Run for 5 seconds
  const unsigned long startTime = millis();

  // Each LED is a potential firefly with its own variables
  struct Firefly {
    bool active;
    unsigned long nextFlashTime;
    unsigned long flashDuration;
    uint8_t maxBrightness;
    int flashPhase; // 0=off, 1=fade in, 2=fade out
  };

  // Initialize array of firefly data
  Firefly fireflies[strip.numPixels()];
  for (int i = 0; i < strip.numPixels(); i++) {
    fireflies[i].active = false;
    fireflies[i].nextFlashTime = startTime + random(0, 1000);
    fireflies[i].flashDuration = random(300, 800);
    fireflies[i].maxBrightness = random(100, 255);
    fireflies[i].flashPhase = 0;
  }

  // Turn all LEDs off initially
  for (int i = 0; i < strip.numPixels(); i++) {
    strip.setPixelColor(i, strip.Color(0, 0, 0));
  }
  strip.show();

  // Run the effect for the specified duration
  while (millis() - startTime < effectDuration) {
    unsigned long currentTime = millis();

    // Update each firefly
    for (int i = 0; i < strip.numPixels(); i++) {
      // Check if it's time to activate a new firefly
      if (!fireflies[i].active && currentTime >= fireflies[i].nextFlashTime) {
        fireflies[i].active = true;
        fireflies[i].flashPhase = 1; // Start fade-in
      }

      // Handle active fireflies
      if (fireflies[i].active) {
        unsigned long elapsedTime = currentTime - fireflies[i].nextFlashTime;

        if (fireflies[i].flashPhase == 1) { // Fade in
          if (elapsedTime < fireflies[i].flashDuration / 2) {
            // Calculate brightness - gentle fade in
            float progress =
                (float)elapsedTime / (fireflies[i].flashDuration / 2);
            uint8_t brightness = progress * fireflies[i].maxBrightness;

            // Softened yellow-green with adjustable brightness
            uint8_t r = (fireflyRed * brightness) / 255;
            uint8_t g = (fireflyGreen * brightness) / 255;
            uint8_t b = (fireflyBlue * brightness) / 255;

            strip.setPixelColor(i, strip.Color(r, g, b));
          } else {
            // Transition to fade out
            fireflies[i].flashPhase = 2;
          }
        } else if (fireflies[i].flashPhase == 2) { // Fade out
          unsigned long fadeOutTime =
              elapsedTime - (fireflies[i].flashDuration / 2);

          if (fadeOutTime < fireflies[i].flashDuration / 2) {
            // Calculate brightness - gentle fade out
            float progress =
                1.0 - ((float)fadeOutTime / (fireflies[i].flashDuration / 2));
            uint8_t brightness = progress * fireflies[i].maxBrightness;

            // Softened yellow-green with adjustable brightness
            uint8_t r = (fireflyRed * brightness) / 255;
            uint8_t g = (fireflyGreen * brightness) / 255;
            uint8_t b = (fireflyBlue * brightness) / 255;
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

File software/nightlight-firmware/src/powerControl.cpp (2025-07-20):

/**
 * Night Light Firmware V1 - Power Control Module Implementation
 * -----------------------------------------------------------
 * Implements power management features for battery-powered night light
 * with periodic battery monitoring during sleep
 *
 * @authors Cameron Gillingham, Claude AI
 * @version 1.2 - Fixed tilt wake-up conflicts with RTC
 */

#include "powerControl.h"
#include "LEDController.h"
#include "config.h"
#include <Arduino.h>

// Flags used by interrupt handlers to communicate with main code
volatile bool wakeFlag = false;
volatile bool rtcWakeFlag = false;

// ISR for pin change - FIXED: Now uses PORTB for tiltSW (PB0)
ISR(PORTB_PORT_vect) {
  // Just set the flag - don't do any processing in ISR
  wakeFlag = true;

  // Clear the interrupt flag for PB0
  PORTB.INTFLAGS = PORT_INT0_bm; // Clear PB0 interrupt flag
}

// ISR for RTC periodic interrupt
ISR(RTC_PIT_vect) {
  // Set flag for battery check
  rtcWakeFlag = true;

  // Clear the interrupt flag
  RTC.PITINTFLAGS = RTC_PI_bm;
}

PowerController::PowerController(uint8_t powerControlPin,
                                 LEDController &ledController)
    : _powerControlPin(powerControlPin), _ledController(ledController),
      _lastActivityTime(0),
      _inactivityTimeout(SLEEP_TIMEOUT_MS), // Default 5 minutes
      _sleepModeEnabled(true), _isInSleepMode(false), _lastBatteryVoltage(0.0),
      _criticalBatteryThreshold(
          CRITICAL_BATTERY_THRESHOLD), // V - shutdown threshold
      _wakeupBatteryThreshold(
          WAKEUP_BATTERY_THRESHOLD), // V - safe to wake up threshold
      _batteryLow(false), _upsideDownDetected(false), _upsideDownStartTime(0),
      _rtcWakeupCounter(0) {}

void PowerController::begin() {
  // Initialize power control pin to active HIGH (keeping power on)
  pinMode(_powerControlPin, OUTPUT);
  digitalWrite(_powerControlPin, HIGH);

  // Initialize the last activity time
  _lastActivityTime = millis();

  // Prepare the tilt sensor interrupt
  pinMode(tiltSW, INPUT_PULLUP);
}

void PowerController::update() {
  // Skip processing if sleep mode is disabled
  if (!_sleepModeEnabled)
    return;

  // Get current time
  unsigned long currentTime = millis();

  // Check if we should enter sleep mode due to inactivity
  if (!_isInSleepMode &&
      (currentTime - _lastActivityTime) > _inactivityTimeout &&
      !_ledController.ledsOn) {
    enterSleepMode();
  }
}

void PowerController::enterSleepMode() {
  // Don't enter sleep if we're already in sleep mode
  if (_isInSleepMode)
    return;

  Serial.println("Entering sleep mode...");
  Serial.flush(); // Ensure message is sent before sleep

  _isInSleepMode = true;
  _rtcWakeupCounter = 0; // Reset counter when entering sleep

  // Configure wake-up interrupt and RTC
  configureInterrupts(true);
  configureRTCWakeup(true);

  // Prepare for sleep mode
  set_sleep_mode(SLEEP_MODE_PWR_DOWN);

  // Sleep loop - stay in sleep until tilt wake-up or critical battery
  while (_isInSleepMode) {
    // Clear flags before sleep
    wakeFlag = false;
    rtcWakeFlag = false;

    Serial.println("Going to sleep...");
    Serial.flush();

    // Enter sleep mode
    sleep_enable();
    sei();       // Ensure interrupts are enabled
    sleep_cpu(); // Enter sleep mode
    sleep_disable();

    Serial.print("Woke up - wakeFlag: ");
    Serial.print(wakeFlag);
    Serial.print(", rtcWakeFlag: ");
    Serial.println(rtcWakeFlag);

    // Check which interrupt woke us up
    if (wakeFlag) {
      Serial.println("Tilt wake-up detected, checking validity...");
      // Tilt sensor wake-up - check if it's a valid wake-up tilt
      if (checkForWakeUpTilt()) {
        Serial.println("Valid tilt wake-up confirmed!");
        wakeUp();
        break;
      }
      Serial.println("Invalid tilt wake-up, continuing sleep...");
      // If not a valid wake-up tilt, continue sleeping
    }

    if (rtcWakeFlag) {
      Serial.println("RTC wake-up for battery check...");
      // RTC wake-up - check battery
      checkBatteryDuringSleep();
      // If battery is critical, we won't return from checkBatteryDuringSleep()
      // Continue sleeping if battery is okay
    }
  }

  // Disable RTC when exiting sleep
  configureRTCWakeup(false);
}

void PowerController::wakeUp() {
  Serial.println("Waking up from sleep mode...");

  // Exit sleep mode
  _isInSleepMode = false;

  // Disable wake-up interrupt and RTC
  configureInterrupts(false);
  configureRTCWakeup(false);

  // Register activity
  registerActivity();

  // Trigger wake-up lighting effect
  _ledController.wakeEffect();
}

void PowerController::checkBatteryDuringSleep() {
  _rtcWakeupCounter++;

  // Only check battery every 10 minutes (600 wake-ups at 1-second intervals)
  if (_rtcWakeupCounter >= 600) { // Check every 10 minutes
    _rtcWakeupCounter = 0;

    Serial.println("Performing battery check during sleep...");

    // Read battery voltage
    uint16_t rawADC = analogRead(battMeasure);
    float batteryVoltage = (rawADC / 1023.0) * 5 * 2;

    Serial.print("Sleep battery voltage: ");
    Serial.println(batteryVoltage);

    // Update battery status
    updateBatteryStatus(batteryVoltage);

    // If battery is critical, shutdown immediately
    if (isBatteryCritical()) {
      Serial.println("Critical battery during sleep, shutting down...");

      // Disable interrupts and RTC before shutdown
      configureInterrupts(false);
      configureRTCWakeup(false);

      // Shutdown - this function doesn't return
      shutdownPower();
    }
  } else {
    // Reduced frequency logging to avoid spam
    if (_rtcWakeupCounter % 60 == 0) { // Log every minute
      Serial.print("RTC wake-up ");
      Serial.print(_rtcWakeupCounter);
      Serial.println("/600");
    }
  }
}

bool PowerController::isInSleepMode() const { return _isInSleepMode; }

void PowerController::registerActivity() { _lastActivityTime = millis(); }

void PowerController::setInactivityTimeout(unsigned long milliseconds) {
  _inactivityTimeout = milliseconds;
}

unsigned long PowerController::getTimeSinceLastActivity() const {
  return millis() - _lastActivityTime;
}

void PowerController::updateBatteryStatus(float voltage) {
  _lastBatteryVoltage = voltage;

  // Check for critical battery level
  if (voltage <= _criticalBatteryThreshold && !_batteryLow) {
    _batteryLow = true;
    shutdownPower();
  }
  // Add hysteresis - we need significantly more voltage to wake back up
  else if (voltage >= _wakeupBatteryThreshold && _batteryLow) {
    _batteryLow = false;
  }
}

bool PowerController::isBatteryCritical() const { return _batteryLow; }

void PowerController::shutdownPower() {
  Serial.println("Shutting down power...");
  Serial.flush();

  // Pull power control pin LOW to turn off MOSFET
  digitalWrite(_powerControlPin, LOW);

  // Note: After this, the device should be powered off
  // It will only turn back on when external power is applied
}
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

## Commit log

2025-02-13 init
    created hardware and software folder and placed up to date dev files in them
    [bom.csv, designators.csv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]
2025-02-13 added current hardware-test file
2025-02-14 made notes and created pin map
    [pin-map.xlsx]
2025-02-14 created new folder for PCB R2
    [nightLight-B_Cu.gbr, nightLight-B_Mask.gbr, nightLight-B_Paste.gbr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]
2025-02-15 pin map
    [pin-map.xlsx]
2025-02-20 Finished schematic, started PCB. Figuring out copper zones
    [bom.csv, designators.csv, nightLight.csv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]
2025-02-21 first PCB layout done
    [nightLight.kicad_pcb]
2025-02-21 Finished first PCB revision
    [nightLight.kicad_pcb, nightLight.kicad_sch]
2025-02-25 refactored entirely, had it working and then broke again
    [LEDController.cpp, config.h]
2025-02-25 Fixed Serial monitor, had clk speed set to 2Mhz instead of 20Mhz
    [main.cpp]
2025-03-11 Finished PCB
    [bom.csv, designators.csv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]
2025-03-11 Touch sensor works to toggle LEDS reliably
2025-03-11 long press adjusting brightness works, some sort of weird grounding issue though
    [config.h, main.cpp]
2025-03-14 Finished new design, needs to be reviewed and rid of errors
    [nightLight.kicad_pcb, nightLight.kicad_sch]
2025-03-15 generated fab files
    [bom.csv, designators.csv, nightLight.kicad_pcb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]
2025-03-16 updated todo
    [bom.csv]
2025-04-13 messing around during testing
    [bom.csv, designators.csv, nightLight.kicad_pcb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]
2025-04-15 trying to fix PCB files
    [bom.csv, designators.csv, positions.csv]
2025-04-15 restored PCB files
    [nightLight.kicad_pcb, nightLight.kicad_sch]
2025-04-15 removed print statements
2025-04-15 Made folder for next PCB revision
    [nightLight.kicad_pcb, nightLight.kicad_sch]
2025-04-15 Check battery once a minute, and also add upper and lower threshold for entering/exiting LOW BATT mode
2025-04-15 less LEDS's, lower brightness max
2025-04-17 kicad was opened
2025-04-18 Added filter to latching cct
2025-04-21 Added LCD cct and broke schematics into different sheets
    [MCU.kicad_sch, chargeController.kicad_sch, nightLight.kicad_sch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]
2025-04-22 finished shematic and added to PCB
    [nightLight.kicad_pcb, vReg.kicad_sch]
2025-04-22 first layout revision
    [MCU.kicad_sch, chargeController.kicad_sch, nightLight.kicad_pcb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]
2025-04-22 PCB rev 3.1 done
    [bom.csv, designators.csv, nightLight.kicad_pcb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]
2025-04-23 seems to be mostly working, but havent tested extensively
    - need to check battery voltage on a timer while asleep
2025-04-23 power control goes low, but does not return high
2025-04-23 rev3 done, errors eliminated
    [MCU.kicad_sch, bom.csv, designators.csv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]
2025-05-21 PCB R3 Finished and ordered
    [bom.csv, designators.csv, nightLight.kicad_pcb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]
2025-05-30 fixed bugs, added wake up effect, extended sleep timeout
    [LEDController.cpp, config.h, powerControl.cpp]
2025-07-06 working on BOM
2025-07-14 reveuwiung board
2025-07-20 things are not working, maybe revert to last commit?
    [config.h, powerControl.cpp]
2025-07-24 drew outline for bodge
    [nightLight.step]
